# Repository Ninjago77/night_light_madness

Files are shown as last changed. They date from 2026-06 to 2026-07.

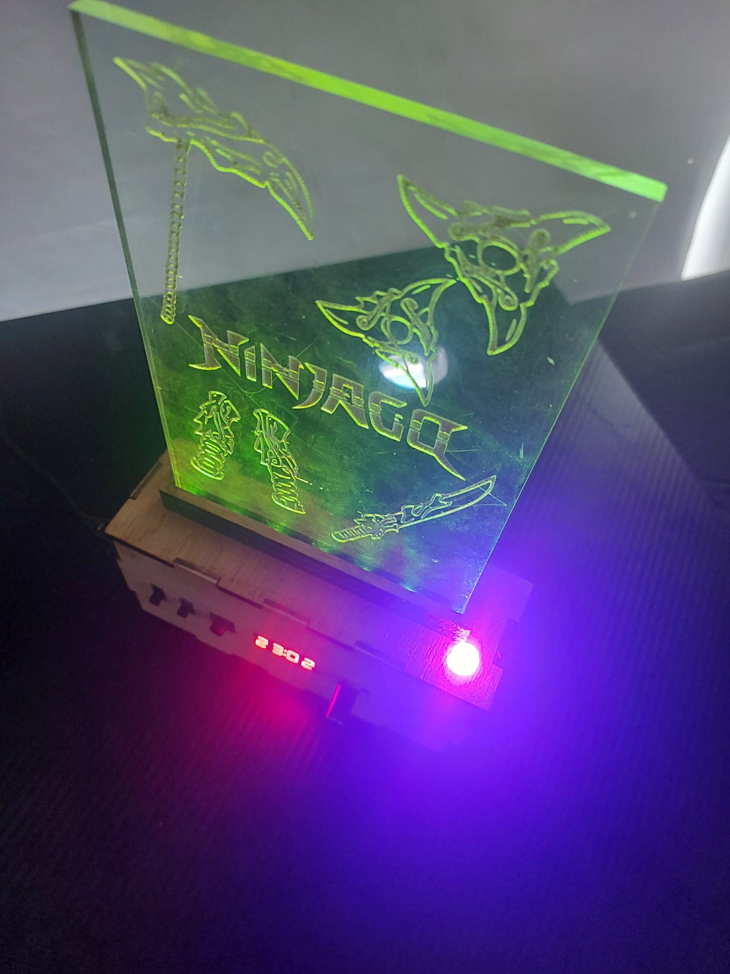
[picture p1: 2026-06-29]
images/WhatsApp Image 2026-06-28 at 13.12.45.jpeg

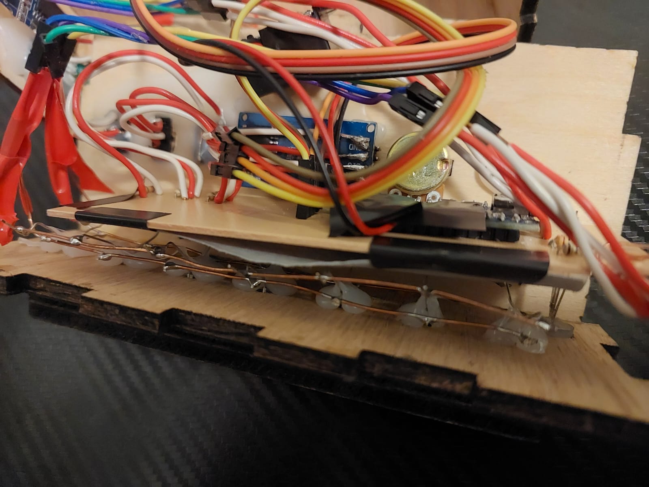
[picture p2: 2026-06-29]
images/WhatsApp Image 2026-06-29 at 01.42.47 (1).jpeg

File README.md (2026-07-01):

# Night Light Madness
An RGB Acrylic Night-Light Alarm Clock with various modes, features & customizability. [Demo Video](https://github.com/Ninjago77/night_light_madness/raw/refs/heads/main/videos/video%201.mp4) `TBD`
## Showcase Gallery
WhatsApp Image 2026-06-28 at 13 12 45WhatsApp Image 2026-06-28 at 13 12 44 (3)WhatsApp Image 2026-06-28 at 13 12 44 (2)
WhatsApp Image 2026-06-28 at 13 12 44 (1)WhatsApp Image 2026-06-28 at 13 12 44WhatsApp Image 2026-06-28 at 13 21 41
## Capabilities

### Here are some of its features, it can be:-
 - Powered with a USB A/C wire
 - Set to a variety of `Modes`, all customizable w/ Code
 - Set to use Any RGB Colour in the Spectrum (or multiple over time)
 - Used to set Alarm(s)
 - Customized with any custom glowing theme
 - Tuned to the light level in the room
 - Enabled to retain time after power loss

## Why?

I wanted a night light that actually expressed myself, so I took my favourite show (Lego Ninjago) & made an acrylic cut with it on:

WhatsApp Image 2026-06-28 at 13 12 45 (1)

Then, I designed a night-light around it capable of glowing in any colour or format I could possibly dream of!

All to show that a person isn't defined by the IKEA furniture that they buy....
And, I think I've achieved that!

## Usage
### It has the following modes (cycle with Pushbutton):-
 - **Mode 1 (White)**: Allows the User to set the Time (Potentiometer) when the Switches are both up (minutes) or when they are both down (hours), opposite directions essentially locks the time.
 - **Mode 2 (~Yellow)**: Allows the User to set a constant Colour of RGBW (Switches) & Brightness (Potentiometer).
 - **Mode 3 (~Magenta)**: Allows the User to set 2 Colours of RGBW to Lerp from (Switches) & the Lerping Speed (Potentiometer).
 - **Mode 4 (~Cyan) `TBD`**: Allows the User to set 3 Colours of RGB/CMY/Random/White to lerp through (Switches), with an exponential Lerping-Speed (Potentiometer)
 - **Mode 5 (Red) `TBD`**: Allows the User to set a constant Colour of RGBW (Switches) but the Brightness will be controlled by the Photoresistor, the sensitivity of which will be controlled by the Potentiometer.
 - **Mode 6 (Green) `TBD`**: Allows the User to set the Alarm Time (Potentiometer) when the Switches are both up (minutes) or when they are both down (hours), opposite directions essentially locks the Alarm time.
 - **Mode 7 (Blue) `TBD`**: Allows the User to set the Auto-Light-Off Time (Potentiometer) when the Switches are both up (minutes) or when they are both down (hours), opposite directions essentially locks the Auto-Light-Off time.

## How to Build? / What are the Materials needed?

The Full List of Materials (& whether they are optional) as well as the Full Build / Recreation Guide are both here: [BUILDME.md](./BUILDME.md)

## Credits & AI Usage
AI used for Minimal Research & Lerp Mathematics only, everything else from design to code all done by @Ninjago77, with the exception of the Ninjago Golden Weapons Fanart.

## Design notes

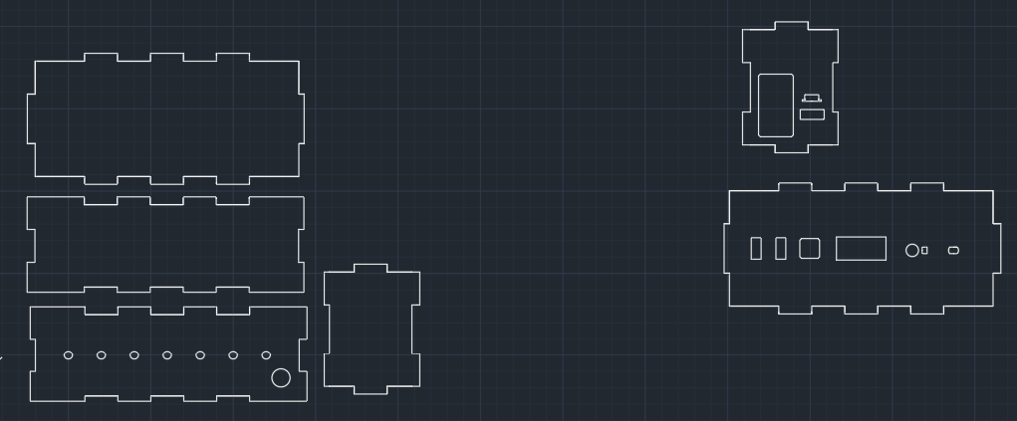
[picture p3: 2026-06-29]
images/Screenshot 2026-06-29 015451.png

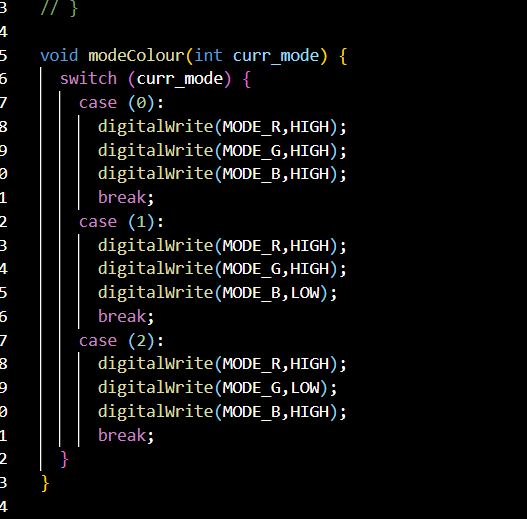
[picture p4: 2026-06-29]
images/Screenshot 2026-06-29 014647.png

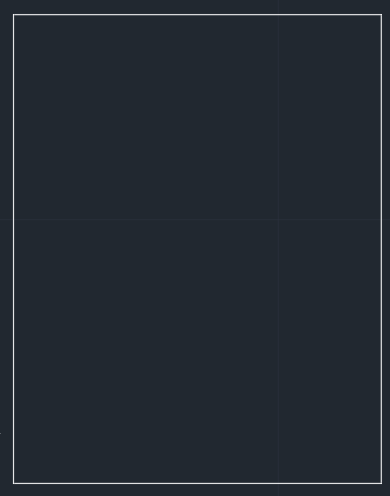
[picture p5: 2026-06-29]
images/Screenshot 2026-06-29 015536.png

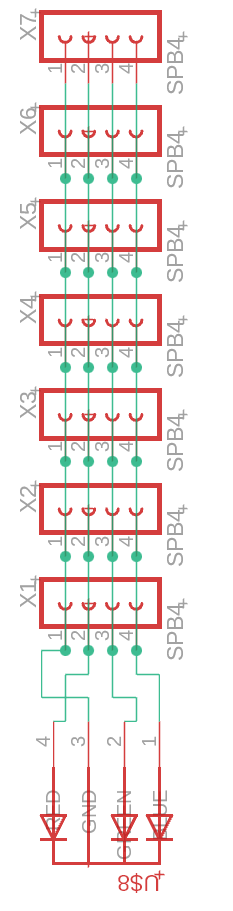
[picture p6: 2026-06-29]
images/Screenshot 2026-06-29 015133.png

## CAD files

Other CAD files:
hardware/case/lamp.dwg
hardware/case/nightlight.dwg
hardware/case/guardrail.dwg
hardware/pcb/Shanvanth's RGB LEDs in parallel.f3z
hardware/pcb/Shanvanth's RGB Madness Night Light Clock Project.f3z

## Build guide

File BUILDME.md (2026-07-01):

# Build Guide - Night Light Madness
## Project Hierachy 
 - [`hardware/case`](./hardware/case): Contains all the 2d AutoCAD (*.dwg*) Design files to laser cut & glue together for making the case & the Acrylic Light Sheet.
 - [`hardware/pcb`](./hardware/pcb): Contains all the Electronics Fusion360 (*.f3z* imports to schematics & pcbs) to put on a pcb & attach/solder components & wires to.
 - [`software/`](./software/): Contains the Arduino Nano's Code to allow the inputs, RTC & Sensors to interact with the LEDs, Display & Buzzer via the Nano.
 - [`images/`](./images/): Contains all the Images taken of the Project or its components/parts.
 - [`videos/`](./videos/): Contains all the Video clips taken of the Project.
 - [`README.md`](./README.md): Provides the introduction, features, usage & overview of the project as well as a gallery of pictures.
 - [`BUILDME.md`](./BUILDME.md): Provides the list of materials & the step-by-step guide to recreate the project / customize it for yourself.
## List of Materials
| Component Name | Quantity | Required + Note | Additional Notes |
| --- | --- | --- | --- |
| 1/4th Inch MDF | 1 Sheet  | Yes (but can be modified for other sizes in files) | To Laser Cut the Parts on the **Left** of [`hardware/case/nightlight.dwg`](./hardware/case/nightlight.dwg) |
| 1/8th Inch MDF | 1 Sheet  | Yes (but can be modified for other sizes in files) | To Laser Cut the Parts on the **Right** of [`hardware/case/nightlight.dwg`](./hardware/case/nightlight.dwg) |
| 1/4th Inch MDF | 3x ; 1 Sheet  | No (but suggested) | To Laser Cut [`hardware/case/guardrail.dwg`](./hardware/case/guardrail.dwg) |
| 1/4th Inch Acrylic | 1 Sheet  | Yes (but can be modified for taller sizes in files) | To Laser Cut a custom stencil of the size in [`hardware/case/lamp.dwg`](./hardware/case/lamp.dwg) |
| Potentiometer (& Dial) | 1x  | Yes (Dial optional) |
| TM1637 4-digit 7-segment Display | 1x | Yes |
| SPDT Switch | 2x | Yes |
| Pushbutton | 1x | Yes |
| Photoresistor | 1x | Yes |
| 10mm Diffused (or not) RGB LED | 1x | Yes |
| 5mm RGB LED | 7x +? | Yes | More/Less could be modified by changing a lot of files (also affects brightness!) |
| DS3231 RTC Module | 1x | No (however it could be present without the battery for shape) |
| CR2032 Lithium Coin Cell Battery | 1x | Not if RTC not present, or if not used |
| USB 2.0 A Male Breakout Board | 1x | No ( if C is present) | A minimum of one power input should be available |
| USB 2.0 C Male Breakout Board | 1x | No ( if A is present) | A minimum of one power input should be available |
| Buzzer Module | 1x | Not required if Alarm isn't needed |
| 10K Ohms Resistor | 4x | Yes |
| 180 Ohms Resistor | 2x | Yes |
| 100 Ohms Resistor | 4x | Yes |
| Arduino Nano | 1x | Yes | Knock-offs should be ok if they work |
## Build Guide
`TBD`
## Build Gallery
WhatsApp Image 2026-06-29 at 01 42 47 (5)WhatsApp Image 2026-06-29 at 01 42 47 (4)WhatsApp Image 2026-06-29 at 01 42 47 (3)
WhatsApp Image 2026-06-29 at 01 42 47 (2)WhatsApp Image 2026-06-29 at 01 42 47 (1)WhatsApp Image 2026-06-29 at 01 42 47
## Screenshot Gallery





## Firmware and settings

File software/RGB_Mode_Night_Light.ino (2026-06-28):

#include <TM1637Display.h>

#define CLK 3
#define DIO 4

#define SPDT1 7
#define SPDT2 2
#define MODEBTN 8

#define LIGHT A3
#define POT A6

#define ACRYLIC_R 9
#define ACRYLIC_G 10
#define ACRYLIC_B 11

#define MODE_R A0
#define MODE_G A1
#define MODE_B A2

// const int RED[] = {255,0,0};
// const int GREEN[] = {0,255,0};
// const int BLUE[] = {0,0,255};
// const int MAGENTA[] = {127,0,127};
// const int YELLOW[] = {127,127,0};
// const int CYAN[] = {0,127,127};
// const int WHITE[] = {255,255,255};
// const int OFF[] = {0,0,0};

TM1637Display display = TM1637Display(CLK, DIO);
double interval = 10000.0; // ms
bool prevBtn = 0;
int mode = 0;
int hours_offset = 0;
int minutes_offset = 0;

int pwmC(int val, int mul) {
  int res = (val*mul)-1;
  if (res <= 0) {res = 0;}
  return res;
}

double mapExponential(double x, double in_min, double in_max, double out_min, double out_max) {
  double expValue = (double)(x - in_min) / (in_max - in_min);
  double mappedValue = pow(expValue, 2);
  return out_min + (mappedValue * (out_max - out_min));
}

double cycleStepGenerator(signed long ms, double interval) {
  int numerator = int(ms % long(interval));
  return numerator/interval;
}
double biDirectionalStepGenerator(signed long ms, double interval) {
  int numerator = int(ms % long(interval*2));
  return abs((numerator-interval)/interval);
}

void lerp(float color1[],float color2[],float value,float result[]){
  result[0] = color1[0] + (color2[0] - color1[0]) * value;
  result[1] = color1[1] + (color2[1] - color1[1]) * value;
  result[2] = color1[2] + (color2[2] - color1[2]) * value;
}

// void linearGradient(float stops[][3],float value,float result[]) { 
//     float stopLength = 1 / (sizeof(stops) - 1);
//     float valueRatio = value / stopLength;
//     int stopIndex = floor(valueRatio);
//     if (stopIndex == (sizeof(stops) - 1)) {
//         return stops[sizeof(stops) - 1];
//     }
//     float stopFraction = valueRatio-int(valueRatio);
//     lerp(stops[stopIndex], stops[stopIndex + 1], stopFraction,result);
// }

void modeColour(int curr_mode) {
  switch (curr_mode) {
    case (0):
      digitalWrite(MODE_R,HIGH);
      digitalWrite(MODE_G,HIGH);
      digitalWrite(MODE_B,HIGH);
      break;
    case (1):
      digitalWrite(MODE_R,HIGH);
      digitalWrite(MODE_G,HIGH);
      digitalWrite(MODE_B,LOW);
      break;
    case (2):
      digitalWrite(MODE_R,HIGH);
      digitalWrite(MODE_G,LOW);
      digitalWrite(MODE_B,HIGH);
      break;
  }
}

void setup() {
  // put your setup code here, to run once:
  Serial.begin(9600);
  display.setBrightness(5);

  pinMode(SPDT1,INPUT);
  pinMode(SPDT2,INPUT);
  pinMode(MODEBTN,INPUT);

  pinMode(LIGHT,INPUT);
  pinMode(POT,INPUT);

  pinMode(ACRYLIC_R,OUTPUT);
  pinMode(ACRYLIC_G,OUTPUT);
  pinMode(ACRYLIC_B,OUTPUT);

  pinMode(MODE_R,OUTPUT);
  pinMode(MODE_G,OUTPUT);
  pinMode(MODE_B,OUTPUT);
}

void loop() {
  signed long milliseconds = (millis() % long(86400000))+(3600000*hours_offset)+(60000*minutes_offset);
  signed long math_only_ms = millis();
  int hours = milliseconds / 3600000;
  int minutes = (milliseconds % 3600000) / 60000;

  bool currbtn = digitalRead(MODEBTN);
  if (currbtn && !prevBtn) {
    mode++;
    if (mode >= 3) {mode = 0;}    
  }

  int pot = analogRead(POT); int intensity;
  // Serial.println(pot);
  if (mode != 0) {
    intensity = map(pot, 0, 1023, 0, 9);
    if (intensity >= 9) {intensity = 8;};
  }

  int light =  analogRead(LIGHT);

  bool spdt1 = digitalRead(SPDT1);
  bool spdt2 = digitalRead(SPDT2);

  // Serial.println(light);
  modeColour(mode);
  switch (mode) {
    case (0):
      analogWrite(ACRYLIC_R,0);
      analogWrite(ACRYLIC_G,0);
      analogWrite(ACRYLIC_B,0);
      if (spdt1 && spdt2) {
        intensity = map(pot, 0, 1023, 0, 24);
        if (intensity >= 24) {intensity = 23;};
        hours_offset = intensity;
      } else if (!spdt1 && !spdt2) {
        intensity = map(pot, 0, 1023, 0, 60);
        if (intensity >= 60) {intensity = 59;};
        minutes_offset = intensity;
      }
      break;
    case (1): // Pure Colours
      if (spdt1) {
        if (spdt2) {
          analogWrite(ACRYLIC_R,pwmC(32,intensity));
          analogWrite(ACRYLIC_G,pwmC(32,intensity));
          analogWrite(ACRYLIC_B,pwmC(32,intensity));
        } else {
          analogWrite(ACRYLIC_R,pwmC(32,intensity));
          analogWrite(ACRYLIC_G,0);
          analogWrite(ACRYLIC_B,0);
        }
      } else {
        if (spdt2) {
          analogWrite(ACRYLIC_R,0);
          analogWrite(ACRYLIC_G,pwmC(32,intensity));
          analogWrite(ACRYLIC_B,0);
        } else {
          analogWrite(ACRYLIC_R,0);
          analogWrite(ACRYLIC_G,0);
          analogWrite(ACRYLIC_B,pwmC(32,intensity));
        }
      }
      break;
    case (2):
      interval = double(mapExponential(int(pot/64), 0, 15, 100, 400)*10);
      Serial.println(interval);
      float color2[3]; // Declare color array here
      float startColor2[3] = {0};
      float endColor2[3] = {0};
      float step2 = biDirectionalStepGenerator(math_only_ms,interval);
      Serial.println(step2);
      if (spdt1) {
        if (spdt2) {
          startColor2[0] = 1.0;startColor2[1] = 1.0;startColor2[2] = 1.0;
          endColor2[0] = 0;endColor2[1] = 0;endColor2[2] = 0;
        } else {
          startColor2[0] = 1.0;startColor2[1] = 0;startColor2[2] = 0;
          endColor2[0] = 0;endColor2[1] = 1.0;endColor2[2] = 0;
        }
      } else {
        if (spdt2) {
          startColor2[0] = 0;startColor2[1] = 1.0;startColor2[2] = 0;
          endColor2[0] = 0;endColor2[1] = 0;endColor2[2] = 1.0;
        } else {
          startColor2[0] = 1.0;startColor2[1] = 0;startColor2[2] = 0;
          endColor2[0] = 0;endColor2[1] = 0;endColor2[2] = 1.0;
        }
      }
      lerp(startColor2, endColor2, step2, color2);
      analogWrite(ACRYLIC_R, color2[0] * 256);
      analogWrite(ACRYLIC_G, color2[1] * 256);
      analogWrite(ACRYLIC_B, color2[2] * 256);
      break;
    // case (3):
    //   interval = double(mapExponential(int(pot/64), 0, 15, 10, 300)*100);
    //   Serial.println(interval);
    //   float color3[3]; // Declare color array here
    //   float startColor3[3] = {0};
    //   float endColor3[3] = {0};
    //   float step3 = biDirectionalStepGenerator(math_only_ms,interval);
  }
  uint8_t dots;
  if ((millis()%1000) >= 500) {dots = 0;} else {dots = 0b01000000;}
  if ((mode == 0) && (spdt1 == spdt2)) {
    display.showNumberDecEx((hours*100)+minutes, dots, true, 4, 0);
  } else {
    display.showNumberDecEx((hours*100)+minutes, 0b01000000, true, 4, 0);
  }
  prevBtn = currbtn;
}

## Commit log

2026-06-29 Enhance BUILDME.md with project details
    Expanded the build guide with detailed project hierarchy and materials preparation.
2026-06-29 Add List of Materials for Night Light Madness
2026-06-29 image add
    [nightlight.dwg]
2026-06-29 Update BUILDME.md with project hierarchy and materials
2026-06-29 Enhance BUILDME.md with materials list and hierarchy
    Added a detailed list of materials required for the project and updated the project hierarchy section.
2026-06-29 Revise BUILDME.md with gallery and materials update
    Updated the build guide to include a gallery section and improved material list formatting.
2026-06-29 added all the images
    [lamp.dwg]
2026-07-01 Revise BUILDME.md with project details and materials
    Updated the build guide to include project hierarchy, materials list, and added a new video directory.
